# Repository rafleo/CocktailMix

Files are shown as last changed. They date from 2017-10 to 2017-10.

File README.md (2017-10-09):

# CocktailMix
An Arduino-based *Thermomix* for cocktails.

Get instructions on how to make a cocktail on a touch display and measure the correct quantity for ingredients using a digital scale.

## Requirements
##### Required hardware
- Arduino board (e.g. Arduino Nano)
- [Nextion NX3224T024_011R](https://nextion.itead.cc) touch display
- HX711 weighing sensor

##### Required software
- [Arduino IDE](https://www.arduino.cc/en/Main/Software) for programming your board
- [HX711 Arduino library](https://github.com/bogde/HX711)
- [Nextion Arduino library](https://github.com/bborncr/nextion)
- [Nextion Editor](https://nextion.itead.cc/resources/download/nextion-editor/) for editing the screen contents

## Schematic

Wire up your Arduino as shown.



The HX711 weighing sensor must be connected to i2c pins, A4 and A5 on the Arduino Nano.

## Getting Started

Flash the *screens.HMI* (located in the Nextion folder) to the display using the Nextion Editor.

Fire up the Arduino IDE and add both Arduino libraries to the IDE by adding them via `Sketch > Include Library > Add .ZIP Library...` and selecting the downloaded ZIP folders.

Now load the *CocktailMix.ino*, check the configuration for the correct pinout and then upload the sketch to your Arduino board.

Once it's up and running, click the cog icon on the start screen of the CocktailMix to tare your scale. You will require an object weighing exactly 1kg. (A package of sugar works nicely, for example.) You should only need to do this once. The result is then stored in EEPROM.

## Known Issues

The `screenMix()` function has not been fully tested yet and it may not work.

The **Arduino Nano** does not have enough memory to cope with the recipes and the required Arrays, so a rewrite to manual steps with if-Statements is necessary to run the CocktailMix on it.

If you continually send commands to the Nextion display in a loop (e.g. `myNextion.setComponentText("instruction", "test value");` on every loop cycle) it will start to return garbled serial messages and thus become unusable (it's then impossible to detect touch events, for example). If your serial window shows output like `DISPLAY: ¿¿¿¿` you will need to check your functions for looped requests to the display. 

## Roadmap

What'd be nice to implement in the future:

- Load recipes from storage, e.g. from an SD card.
- Ability to 'scroll' through recipes on the start screen.
- Download cocktail recipes from an online service with an API (over WiFi) and store them on the SD card.

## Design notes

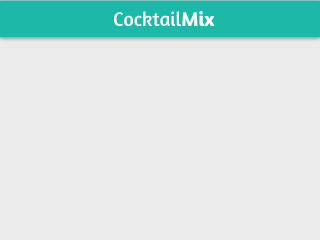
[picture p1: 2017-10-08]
Nextion/bg-screen.png

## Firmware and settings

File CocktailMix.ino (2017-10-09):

/**********************************
  
  CocktailMix v1

***********************************

  Leonardo Re
  
  mail@leonardo.re
  https://leonardo.re

***********************************/

#include <SoftwareSerial.h>
#include <EEPROM.h>

// https://github.com/bborncr/nextion
#include <Nextion.h>

// https://github.com/bogde/HX711
#include <HX711.h>


/**********************************
  Load variables
***********************************/

// Nextion TX to pin 2 and RX to pin 3 of Arduino
SoftwareSerial nextion(2, 3);
Nextion myNextion(nextion, 9600);
HX711 scale;

String curPage = "start";
String curCocktail = "";
byte i = 0;
byte previous_percentage = 0;
byte percentage = 0;
byte instruction = 0;
int scaleinit = 0;
struct st_t { long lo; byte by; double db; };
float scale_set;
byte buzzer = 9;

byte steps = 0;
byte cocktailloop = 0;

byte stepType[]={0};
byte stepTypeMeasurement[]={0};
String stepInstruction[]={""};

/*
 * 
 * NANO SETTINGS:
 * nextion(2, 3);
 * buzzer = 9;
 * 
 * NANO PINS:
 * D3 - Gelb Nextion
 * D2 - Blau Nextion
 * GND - Schwarz Nextion
 * 
 * D9 - Rot Pieper
 * 
 * A4 - Weiß Waage
 * A5 - Grau Waage
 * +5V - Lila Waage
 */


/**********************************
  Setup
***********************************/

void setup() {
  Serial.begin(9600);
  Serial.println("**********************");
  Serial.println("*   CocktailMix v1   *");
  Serial.println("**********************");
  Serial.println("");
  Serial.print("Initialising ...");

  pinMode(buzzer, OUTPUT);

  myNextion.init();
  myNextion.sendCommand("page start");
  myNextion.setComponentText("instruction", "Select a drink.");

  // HX711.DOUT   - pin #A4
  // HX711.PD_SCK - pin #A5
  scale.begin(A4, A5);
  
  // check if scale calibration on device, otherwise load default
  if (EEPROM_readAnything(0, scale_set)) { 
    scale.set_scale(scale_set);
  } else {
    // default: 2112.66
    scale.set_scale(2112.66);
  }
  scale.tare();
  scaleinit = scale.read_average(5);
  
  Serial.println(" done!");
  Serial.println("");
}



/**********************************
  Main loop
***********************************/

void loop() {

  if (curPage == "start") {
    screenHome();
  } else if (curPage == "calibrate") {
    screenCalibrate();
  } else if (curPage == "tare") {
    screenTare();
  } else if (curPage == "mix") {
    screenMix();
  } else if (curPage == "done") {
    screenDone();
  }

}


/**********************************
  Display / screen functions
***********************************/


void screenDone() {

  if (i == 0) {
    myNextion.setComponentText("instruction", "Enjoy your "+curCocktail+"!");
    i = 1;
  }

  delay(200);
  i++;

  if (i >= 25) {
    curCocktail = "";
    myNextion.sendCommand("page start");
    curPage = "start";
    i = 0;
  }
  
  String input = listenDisplay();
  if (input.startsWith("65 4 ")) {
    curCocktail = "";
    myNextion.sendCommand("page start");
    curPage = "start";
    i = 0;
  }
}




void screenMix() {
  // if we land here by error, reset
  if(curCocktail == "") { curPage = "start"; }

  String input = listenDisplay();
  if (input == "65 3 5 0 ffff ffff ffff") {
    // abort & return home
    Serial.println("Cancelling - back to start.");
    curCocktail = "";
    myNextion.sendCommand("page start");
    curPage = "start";
    i = 0;
  }


  // Glas: 250ml (~250g)
  if (steps == 0) {
    if (curCocktail == "Mojito") {
      // load recipe
      
      // Step types:
      // 0 = instruction only (with OK button)
      // 1 = measurement
  
      // Step type measurements in ml (= gram)
      
      steps = 6;
      byte stepType[]={0,0,0,0,1,1};
      byte stepTypeMeasurement[]={0,0,0,0,50,60};
      String stepInstruction[]={
        "Divide a lime into eights and add it."
        "Add 2 teaspoons of brown sugar.",
        "Add 8 leaves of mint. Pestle the contents.",
        "Fill glass with crushed ice.",
        "Add 5cl white rum.",
        "Add 6cl soda."
      };
    }
  
    if (curCocktail == "Long Island Ice Tea") {
      // load recipe
      
      steps = 9;
      byte stepType[]={0,1,1,1,1,1,1,0,0};
      byte stepTypeMeasurement[]={0,20,20,10,20,10,20,0,0};
      String stepInstruction[]={
        "Add ice cubes."
        "Add 2cl brown rum.",
        "Add 2cl gin.",
        "Add 1cl lime juice.",
        "Add 2cl vodka.",
        "Add 1cl orange liqueur.",
        "Add 2cl orange juice.",
        "Add a pinch of sugar and shake well.",
        "Top up with coke."
      };
    }

  }
  
  makeCurrentCocktail();
  
}


void screenTare() {
  // if we land here by error, reset
  if(curCocktail == "") { curPage = "start"; }

  if (i == 0) {
    myNextion.setComponentText("instruction", "Place your glass on the scale.");
    myNextion.sendCommand("vis okay,1");
    i = 1;
  }

  /* EXPERIMENT: DETECT GLASS AUTOMAGICALLY 
  int scalecurrent = scale.read_average(5);
  Serial.print("Init: ");
  Serial.print(scaleinit);
  Serial.print(" - Current: ");
  Serial.println(scalecurrent);
  if (scalecurrent > (scaleinit+200) || scalecurrent < (scaleinit+200)) {
    delay(5000);
    // Automatic glass detection
    scale.tare();
    myNextion.sendCommand("page mix");
    i = 0;
    curPage = "mix";
  }
  */

  String input = listenDisplay();
  if (input == "65 2 5 0 ffff ffff ffff") {
    // abort & return home
    Serial.println("Cancelling - back to start.");
    curCocktail = "";
    myNextion.sendCommand("page start");
    curPage = "start";
    
  } else if (input == "65 2 4 0 ffff ffff ffff") {

    Serial.println("OK pressed. Setting scale now.");
    scale.tare();
    myNextion.sendCommand("page mix");
    i = 0;
    curPage = "mix";
    
  }

}



void screenCalibrate() {

  if (i == 0) {
    myNextion.sendCommand("vis okay,0");
    myNextion.setComponentText("instruction", "Please wait, measuring");
    
    Serial.println("READING SCALE");
    Serial.print("read: \t\t");
    Serial.println(scale.read());      // print a raw reading from the ADC
  
    Serial.print("read average: \t\t");
    Serial.println(scale.read_average(20));   // print the average of 20 readings from the ADC
    
    Serial.print("get value: \t\t");
    Serial.println(scale.get_value(5));   // print the average of 5 readings from the ADC minus the tare weight (not set yet)
  
    scale.set_scale();
    delay(1000);
    scale.tare();
  
    myNextion.setComponentText("instruction", "Place 1kg on the scale and press ok.");
    myNextion.sendCommand("vis okay,1");
    i = 1;
  }

  String input = listenDisplay();
  if (input == "65 2 5 0 ffff ffff ffff") {
    // abort & return home
    Serial.println("Cancelling - back to start.");
    curCocktail = "";
    myNextion.sendCommand("page start");
    curPage = "start";
    i = 0;
    
  } else if (input == "65 2 4 0 ffff ffff ffff") {

    Serial.println("OK pressed. Calibrating ...");

    float reading = scale.get_units(10);
   
    Serial.print("get units: \t\t");
    Serial.println(reading);

    float result = reading/1000;
    Serial.print("DIVIDING ");
    Serial.print(reading);
    Serial.print(" / 1000 = ");
    Serial.println(result);

    // save calibration
    EEPROM_writeAnything(0, result);
    scale.set_scale(result);
    scale.tare();

    Serial.println("..................................");
    Serial.println("After setting up the scale:");

    Serial.print("read: \t\t");
    Serial.println(scale.read());                 // print a raw reading from the ADC
  
    Serial.print("read average: \t\t");
    Serial.println(scale.read_average(20));       // print the average of 20 readings from the ADC
  
    Serial.print("get value: \t\t");
    Serial.println(scale.get_value(5));    // print the average of 5 readings from the ADC minus the tare weight, set with tare()
  
    Serial.print("get units: \t\t");
    Serial.println(scale.get_units(5), 1);        // print the average of 5 readings from the ADC minus tare weight, divided
              // by the SCALE parameter set with set_scale
              
    Serial.println("..................................");
    
  }

}


void screenHome() {
  
  // Mojito:      65 1 3 0 ffff ffff ffff
  // Long Island Ice Tea:  65 1 4 0 ffff ffff ffff

  // @TODO: BUTTONS DEFINIEREN! z.B. Long Island Ice Tea

  String input = listenDisplay();
  if (input == "65 1 3 0 ffff ffff ffff") {

    Serial.println("--> Mojito it is!");
    curCocktail = "Mojito";
    myNextion.sendCommand("page tare");
    curPage = "tare";
    
  } else if (input == "65 1 4 0 ffff ffff ffff") {
    
    Serial.println("--> Long Island Ice Tea it is!");
    curCocktail = "Long Island Ice Tea";
    myNextion.sendCommand("page tare");
    curPage = "tare";
    
  } else if (input == "65 1 6 0 ffff ffff ffff") {
    
    Serial.println("SETTINGS OPENED");
    myNextion.sendCommand("page tare");
    curPage = "calibrate";
    
  }
  
}


/**********************************
  Cocktail-instruction loop
***********************************/

void makeCurrentCocktail() {

/*
  As a reminder, here's how we structured
  the cocktail information:

  steps = 6;
  byte stepType[6]={0,0,0,0,1,1};
  byte stepTypeMeasurement[6]={0,0,0,0,50,60};
  String stepInstruction[6]={
    "Divide a lime into eights and add it."
    "Add 2 teaspoons of brown sugar.",
    "Add 8 leaves of mint. Pestle the contents.",
    "Fill glass with crushed ice.",
    "Add 5cl white rum.",
    "Add 6cl soda."
  };

*/

  if (cocktailloop > steps+1) {
    
    // all steps executed, ending instructions
    
    Serial.println("--- END INSTRUCTIONS ---");
    myNextion.sendCommand("page done");
    instruction = 0;
    percentage = 0;
    previous_percentage = 0;
    curPage = "done";
    cocktailloop = 0;
    i = 0;
    steps = 0;
    byte stepType[]={0};
    byte stepTypeMeasurement[]={0};
    String stepInstruction[]={""};
    sendTone("done");
    
  } else {
    
    // we're still in the making of something great ;)

    // check if we need to refresh the screen
    if (instruction <= cocktailloop) {
      Serial.println("--- NEW INSTRUCTIONS ---");
      Serial.print("Current loop: ");
      Serial.println(cocktailloop);
      Serial.print("Total steps: ");
      Serial.println(steps);
      
      if (stepType[cocktailloop] == 1) {    
        Serial.println("Type: measurement");
        myNextion.sendCommand("page mix");
        myNextion.setComponentText("instruction", stepInstruction[cocktailloop]);
        myNextion.setComponentValue("status", 0);
      } else {
        Serial.println("Type: instruction only");
        myNextion.sendCommand("page tare");
        myNextion.setComponentText("instruction", stepInstruction[cocktailloop]);     
      }
      instruction++;
    }

    // check what we're waiting for
    if (stepType[cocktailloop] == 1) {
      // we're waiting for the correct weight
      float weight = scale.get_units(1);
      previous_percentage = percentage;
      percentage = weight/stepTypeMeasurement[cocktailloop]*100;
      if (percentage < 0) percentage = 0;
      if (percentage > 100) percentage = 100;
      if (previous_percentage != percentage) {
        myNextion.setComponentValue("status", percentage);
      }
  
      Serial.print("Weight: ");
      Serial.println(weight);
  
      if (weight >= stepTypeMeasurement[cocktailloop]) {
        sendTone("buzz");
        scale.tare();
        weight = 0;
        cocktailloop++;
      }
      
    } else {
      // we're waiting for a button press
      String input = listenDisplay();
      if (input == "65 2 4 0 ffff ffff ffff") {
        sendTone("buzz");
        cocktailloop++;
      }
      
    }

    
  }
  
  
}



/**********************************
  General functions
***********************************/

// Wait for touch input

String listenDisplay() {
  String message = myNextion.listen();
  if(message != ""){
    Serial.println("DISPLAY: "+message);
    return message;
  }
}


// Make the beeper output the selected melody

void sendTone(String melody) {
  if (melody == "buzz") {
    tone(buzzer, 1000);
    delay(150);
    noTone(buzzer);
    delay(150);
    tone(buzzer, 1000);
    delay(150);
    noTone(buzzer);
  } else if (melody == "done") {
    tone(buzzer, 1000);
    delay(250);
    tone(buzzer, 1500);
    delay(250);
    tone(buzzer, 2000);
    delay(250);
    noTone(buzzer);
  }
}


/**********************************
  EEPROM function
***********************************/

// Taken from https://playground.arduino.cc/Code/EEPROMWriteAnything

template <class T> int EEPROM_writeAnything(int ee, const T& value)
{
   const byte* p = (const byte*)(const void*)&value;
   int i;
   for (i = 0; i < sizeof(value); i++)
       EEPROM.write(ee++, *p++);
   return i;
}

template <class T> int EEPROM_readAnything(int ee, T& value)
{
   byte* p = (byte*)(void*)&value;
   int i;
   for (i = 0; i < sizeof(value); i++)
       *p++ = EEPROM.read(ee++);
   return i;
}

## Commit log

2017-10-09 Added schematic to README
2017-10-09 Added Fritzing diagram file
    [CocktailMix.fzz]
